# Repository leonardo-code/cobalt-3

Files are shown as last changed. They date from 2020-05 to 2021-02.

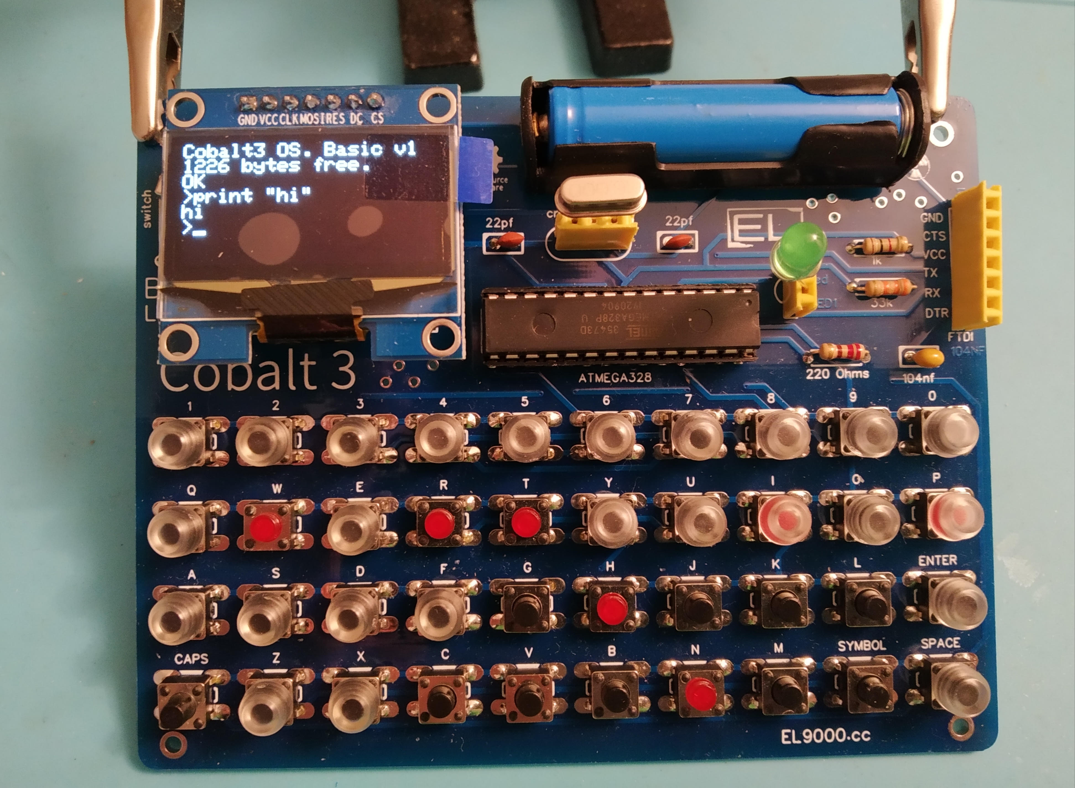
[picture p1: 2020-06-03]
img/Cobalt3.jpg

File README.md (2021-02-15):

# cobalt-3
Cobalt 3 pocket computer

by Leonardo Leoni

I wanted a pocket computer I can build myself to learn through-hole soldering and get a simple basic computer. There were a lot of projects out there, ok, but I needed a kit ready to mount, without having to look for components around the world.

The core component is the Atmega328, the keyboard is serial with tactile momentary switches and the display an is a SPI OLED type with the common SH1106 driver. A toggle switch and a led complete the Cobalt 3 (giving a name was the most cool part of the job).

I put all together in the design of a simple pcb and I used an Arduino IDE to compile the O.S. in C++ language. The O.S. can be loaded through a UART serial interface. The O.S. is composed of 3 parts: one to show data on the display (data output), one to manage the keyboard (data input), and last but not least, to elaborate the Basic Language instructions (data elaboration).

Project page:
http://el9000.cc/projects

Shop: https://www.tindie.com/products/el9000/cobalt-3-a-pocket-computer-diy/

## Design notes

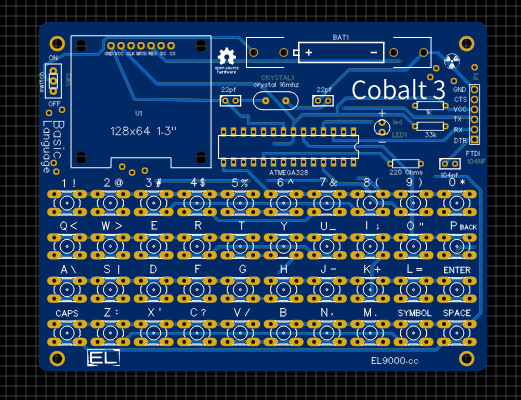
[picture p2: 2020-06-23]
doc/gerber/pcb.gif

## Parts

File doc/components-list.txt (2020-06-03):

1	×	Oled Display 128x64 SPI 7 pins
1	×	AAA battery holder
1	×	led
40	×	tactile momentary switches
1	×	220 Ohm resistor
1	×	1 K Ohm resistor
1	×	33 K Ohm resistor
1	×	AAA Li-Ion battery 3.7v 350-600 mAh
1	×	Crystal 16.000 MHz
2	×	22pf capacitor
1	×	104nf capacitor
1	×	atmega328p
1	×	socket 28 pin narrow
1	×	header 6 pin
1	×	toggle switch 3 pin

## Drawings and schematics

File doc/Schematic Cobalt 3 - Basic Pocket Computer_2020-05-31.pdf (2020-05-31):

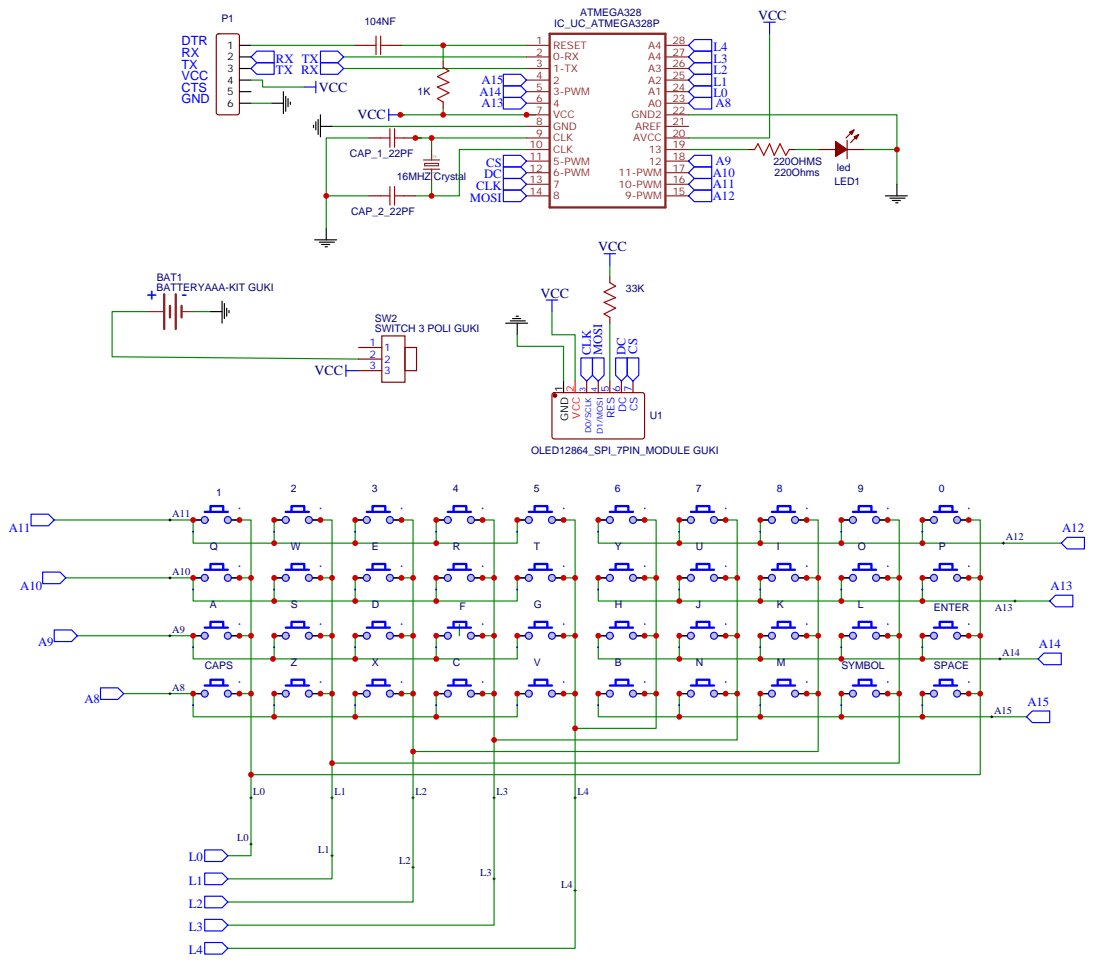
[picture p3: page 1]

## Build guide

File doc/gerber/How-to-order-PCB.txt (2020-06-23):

How to Order PCB

Please refer to:
https://docs.easyeda.com/en/PCB/Order-PCB

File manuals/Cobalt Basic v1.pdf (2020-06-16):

17/6/2020 | Cobalt Basic v1
el9000.cc/Cobalt_Basic_v1 | 1/7

## Cobalt Basic v1

# User Manual

by Leonardo Leoni

Why the Basic language?
The Basic language was the first language to be "user-friendly", easy to learn and to understand. It uses an interpreter, so you can write a command after the prompt and run it immediately. It was the first simple computer language and became very common in the home computer sector during the 80's.

What is the Cobalt Basic language?
Cobalt Basic is one version of the Tiny Basic language developed initially as Palo Alto Tiny Basic by Li-Chen Wang (1976) and it ran on either the 8080 or Z80 processor. Nowadays there are some very similar versions that run on ATmega328, some are the TOYOSHIKI Tiny BASIC for Arduino, the Tiny Basic 68k by Gordon Brandly, the Arduino Basic by Michael Field and the Tiny Basic Plus by Scott Lawrence. Many credits to those guys.
Cobalt Basic is nothing more that a simpler version, adapted to stay into a little atmega328 together with the display and keyboard libraries, leaving also the space for your program to be put in the memory.

What can Cobalt Basic do?
Ok, but again: why the Basic Langauge? Because it's the perfect language if you don't know anything about programming, because it's simple but complete. Think about that: with this computer language you can print words on the screen, give value to variables, make simple mathematical calculation, use subroutines, repeat commands also infinitely and do much more.

Does it include a standard keyboard?
Only two words about the keyboard. It's important to understand the keyboard layout, a QWERTY one but with several particularities, so take two minutes to give a look to the Cobalt 3 keyboard guide before using it.

Characters typed with the keyboard are lowercase, but the Cobalt Basic commands are stored in memory uppercase, so you can see the difference from what you type and what is stored. It's useful when you subsstitute a row of the program with another one. Type LIST command to see your program uppercase.
Example:

>10 prit "dog"
>run

Syntax Error
>10 print "dog"
>list
10 PRINT "dog"
>run
dog

OK
>_

"Syntax Error" is the error message when there's a mistake in your program.

So, what else, let's start with Cobalt Basic! Let's look together at the commands available!

Summary
Relational operators
Arithmetic operations
NEW - clears the last program RUN - executes the current program
LIST - prints the current program
LET - sets the value of a variable
IF - if expression is true, elaborates an istruction GOTO - continues execution at a given line number GOSUB - goes to a subroutine at a given line number RETURN - returns from a subroutine
REM - comments
FOR - loop block, uses TO and STEP
TO - the end value that stops the for loop
STEP - adds a different value in a for loop
NEXT - end of for block
INPUT - gives to the user the chance of insert a value for a variable PRINT - displays something on the screen, also "?"
STOP - ends the execution of the current program
BYE - exits, a soft reboot of the Cobalt device

Relational operators
The Cobalt Basic v1 has six relational operators used to compare two operands, obtaining a true/false result.
= equality
< less than
> greater than
<= less or equal
>= greater or equal
<> not equal

Arithmetic operations
The Cobalt Basic v1 can do four arithmetic operations. It can add, substruct, multiply and divide.
+ add
- substruct
* multiply
/ divide

NEW
Use this command at the Cobalt prompt when you want to clear the memory and start a new program. It cancels an old program, lines, or commands, clearing all.

>new
>list
OK

RUN
This is the command you need to launch the program you wrote.
A program is made of several rows, each one has an instruction to execute.
At the beginning of each row you can write the number of the row. If you do it, the row will be part of the current program.
The numbers are for ordering the statements of the program.
Without the number at the beginning of the row, the instruction will be executed immediately from the Cobalt Basic interpreter.

>run

See the example in the LET statement.

LIST
The statement is used to view the program you are typing or you finished.

>list

See the example in the STEP statement.

LET
This instruction assigns a value to a variable. The value could be a number or another variable.

>10 let p=1+7
>20 print p
>run
8
OK

IF
It checks if an expression is true, and if so, an inline instructions will be executed.

The relational operators are:
= equality
< less than
> greater than
<= less or equal
>= greater or equal
<> not equal

Examples:

>10 a=3
>20 if a > 2 print "hi"
>run
hi
OK

GOTO
The GOTO statement has the line number where the program execution will continue, jumping to that line.
Example:

>10 a=2
>20 a=a+1
>30 print a
>40 if a < 10 print a
>50 if a < 5 goto 20
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
GOSUB
The GOSUB statement has the line number where the program execution will continue, similar to GOTO, with a difference: the block that will be executed (subroutine) ends with the keyword RETURN.
So in this case, the excution will jump back to the line after the GOSUB statement. Consider also the use of STOP to exit the program execution.

>10 z = 2
>20 z = z + 1
>30 gosub 300
>40 if z < 5 goto 20
>50 stop
>300 rem subroutine for printing >310 print z
>320 return
>run
3
4
5
OK

RETURN
The RETURN keyword indicates the end of a subroutine called by a GOSUB.

REM
After a line number, the word REM is used to write a comment, in this way:

>20 rem Program about financial calculation

FOR
The FOR keyword is used for repeating a block of istructions. How does it work?

Let's look at the example below.

>10 for t=2 to 5
>20 print t
>30 next t
>run
2
3
4
5
OK

After the FOR keyword, "t=2" is the initial value of "t", while "to 5" means the FOR block will be repeated until the value of "t" will be "5".
In the FOR block there's the command "print t", that means the value of "t" will be displayed.
The row with "next t" indicates the end of the loop.

TO
In a FOR loop, after the starting value, the block will be repeated until the end value, showed after the "to" keyword.
See the example in the FOR statement.

STEP
Substituting the row number 10, this is what will happen:

>10 for t=2 to 10 step 2
>list
10 FOR T=2 TO 5
20 PRINT T
30 NEXT T
>run
2
4
6
8
10
OK

That's because adding "step 2" means add "2" to the value of "t";

NEXT
The statement that marks the end of a FOR loop. It means "next round"; Example:

>30 next t

INPUT
With this command a usser can assign a number to a variable.
Below, when I run the program, I write "2" after the "?", and the program assigns it to the variable a. Then it prints its value.
See also the use of the command LIST.

>10 input a
>20 print a
>list
10 INPUT A
20 PRINT A
OK
>run
?2
2
OK
>_

PRINT
Used to make the program write something on the screen. After the execution,the system shows the prompt and the cursor.

>print "hello"
hello
>_

If you add a semicolon at the end, the Cobalt Basic interpreter writes the commands inline, so you have:

>print "hello";
hello>_

STOP
This command ends the execution of the program. See the example in the GOSUB statement.

BYE
This is a system command, you can use it if you need a soft reboot of the system with the reset of the memory.

>bye
1226 bytes free.
OK
>_

Thanks for reading.

Cheers,

Leonardo

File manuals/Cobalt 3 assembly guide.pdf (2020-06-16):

17/6/2020 | Cobalt 3 assembly guide

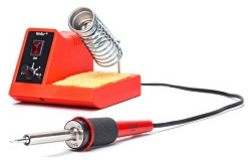
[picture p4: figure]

el9000.cc/Cobalt_3_assembly_guide | 1/10

## Cobalt 3

# Assembly guide

by Leonardo Leoni

Introduction
First of all note that this pocket computer is for hobby use, it is not for industrial use.
Cobalt 3 has been designed to give everyone the opportunity to build their own computer in the easiest way possible. This allows you to have fun learning and building something that is complete and functional, within limits.

Assembling a computer is very complex even if it is supplied as a kit to assemble. For this reason I realised this project: to give everyone the opportunity to make a computer on their own. And to make it easier, this little computer is a sbc (single board computer). This means that all the necessary components are on a single electronic board.

Also included are a display and a keyboard, to avoid having to plug it into another computer to see what goes on the screen or to type commands.
A battery is also included in the card, so you can put Cobalt 3 in your pocket and carry it with you, when you go out or go to school or work.

Required Skills
Assembling. Although the list of components is kept to the minimum, there are about 200 soldering points, which means that you need some experience. I started from scratch, and I took other less complex kits to learn how to solder.
So you should be able to assemble beforehand that this step has been taken.

Tools

You just need normal soldering tools as a soldering iron, a magnifying glass, and a third-hand tool for holding the board, etc

Here a link to an easy soldering tutorial for beginners:
Soldering Tutorial for Beginners: Five Easy Steps (https://www.youtube.com/watch?v=Qps9woUGkvI)

Components
Note that components and board images can be different in shape and color.

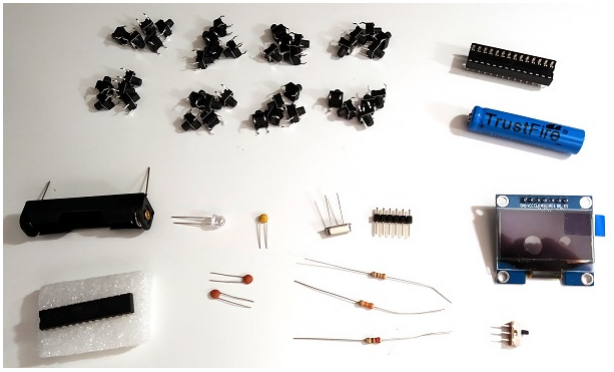
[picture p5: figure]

Try to visualize where the various components go on the board. Then assemble the board in different steps.
I suggest to start with the smaller parts.

List:
1 × atmega328p
1 × Oled Display 128x64 SPI 7 pins
1 × AAA battery holder
1 × socket 28 pin narrow
1 × AAA Li-Ion battery 3.7v 350-600 mAh 1 × Crystal 16.000 MHz
1 × led
1 × 220 Ohm resistor
1 × 1 K Ohm resistor
1 × 33 K Ohm resistor
2 × 22pf capacitor
1 × 104nf capacitor
1 × header 6 pin
1 × toggle switch 3 pin
40 × tactile momentary switches

This is how It will look at the end.

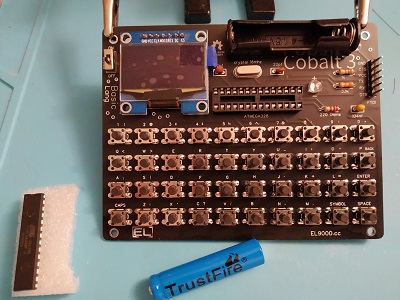
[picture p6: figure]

1) Tactile momentary switch

First insert and solder all 40 switches on the keyboard

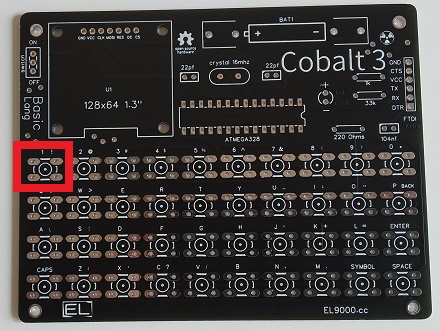
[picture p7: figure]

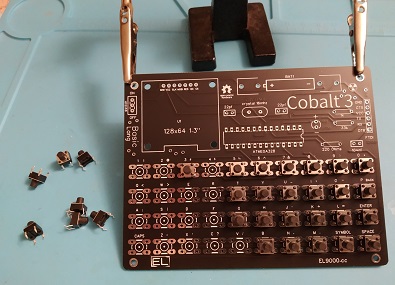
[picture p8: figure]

2) Resistors and capacitors

In the green rectangle 2 x capacitors 22pf
In the red one 1 x capacitor 104nf
In the blue one 3 x resistors, from the top to bottom:
- 1K Ohm resistor
- 33K Ohm resistor
- 220 Ohm resistor

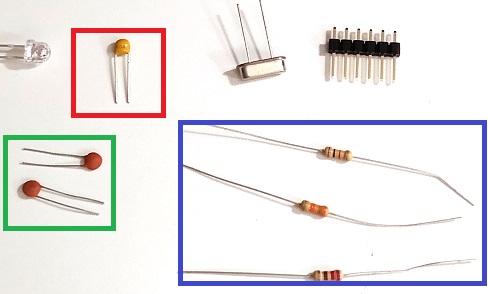
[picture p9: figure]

Put the resistors on the board in the same order. Match the color of the rectangles.

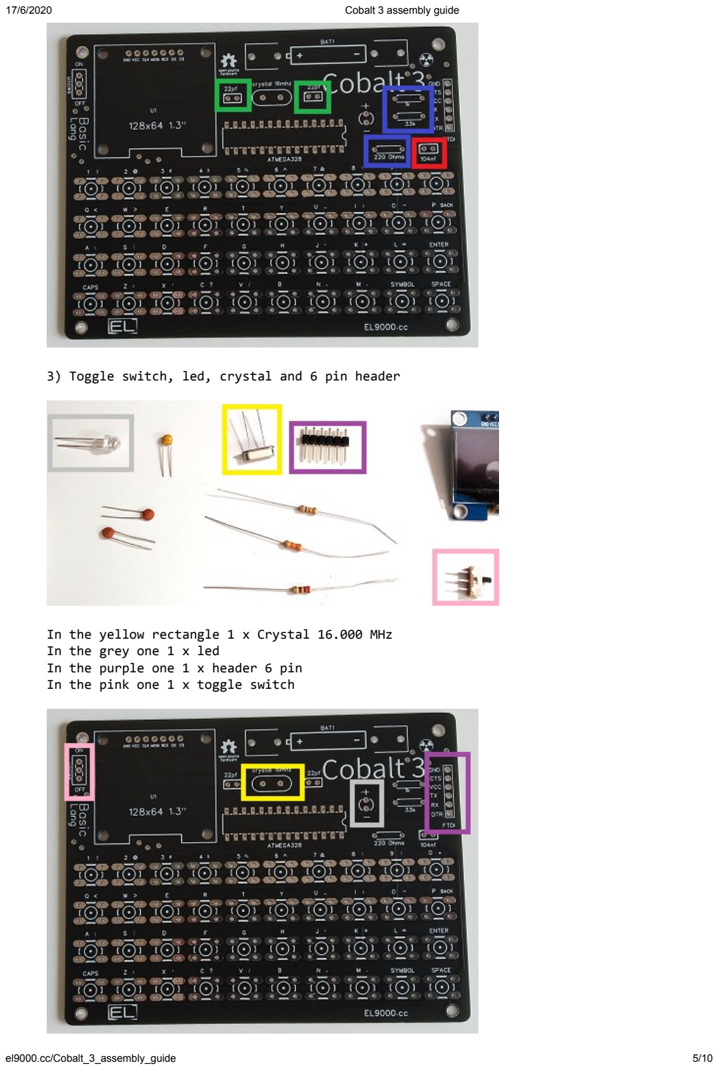
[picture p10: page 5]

3) Toggle switch, led, crystal and 6 pin header

In the yellow rectangle 1 x Crystal 16.000 MHz In the grey one 1 x led
In the purple one 1 x header 6 pin
In the pink one 1 x toggle switch

Match the color of the rectangles.
Pay attention to the legs of the led, the longer is the positive, the shorter the negative.
4) Microcontroller socket and battery holder

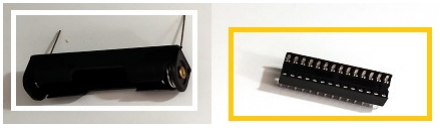
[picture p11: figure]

In the white rectangle 1 x battery holder In the orange one 1 x socket

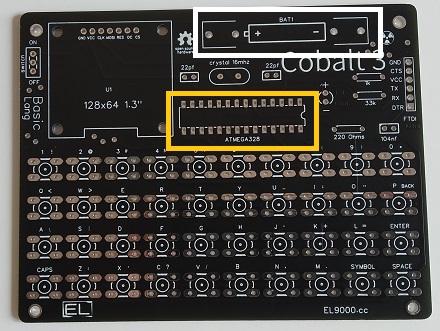
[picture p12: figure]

Pay attention to the right position of those components.
There is a notch on the socket and on the atmega328 that shows you what the right fitting is.
Fit correctly the positive and the negative side of the battery holder.
4) Oled display

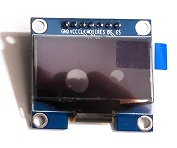
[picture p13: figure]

Fit it in the light blue color rectangle. Pins name can be different, don't worry about it, only the right position of the component is important.

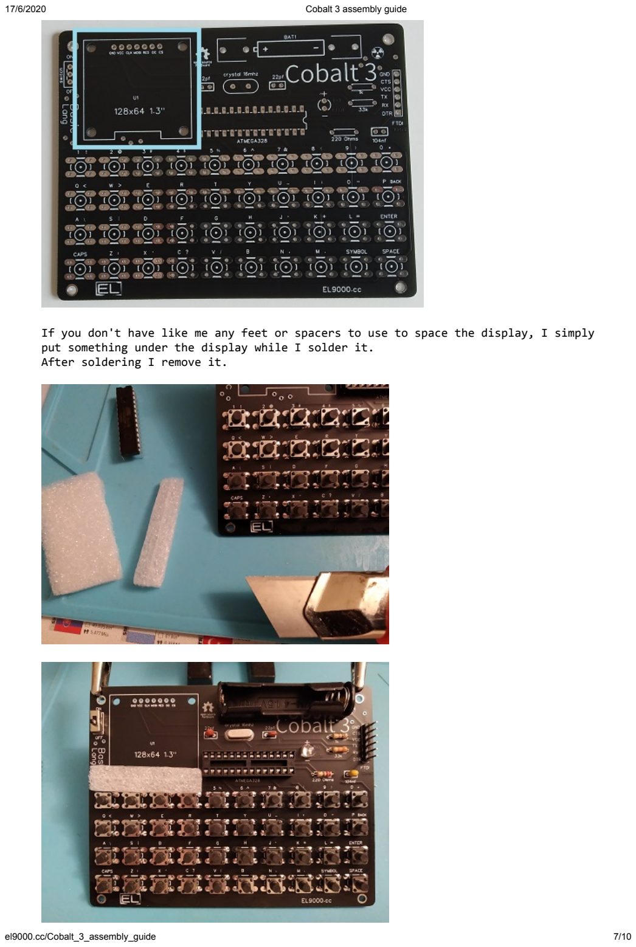
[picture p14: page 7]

If you don't have like me any feet or spacers to use to space the display, I simply put something under the display while I solder it.
After soldering I remove it.

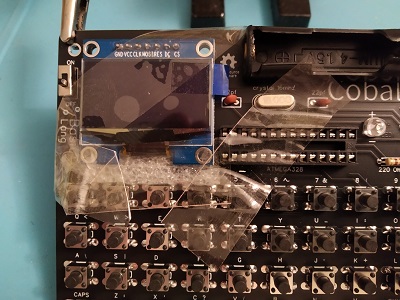
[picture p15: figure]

Finishing and Cleaning
When you're done assembling, fit the microcontroller in the socket and then clean the board.
Cleaning the board is a good practice, I use Isopropyl alcohol because is highly efficient in dissolving most commonly found PCB contaminants, it's also electrically non-conducting and evaporates quickly.

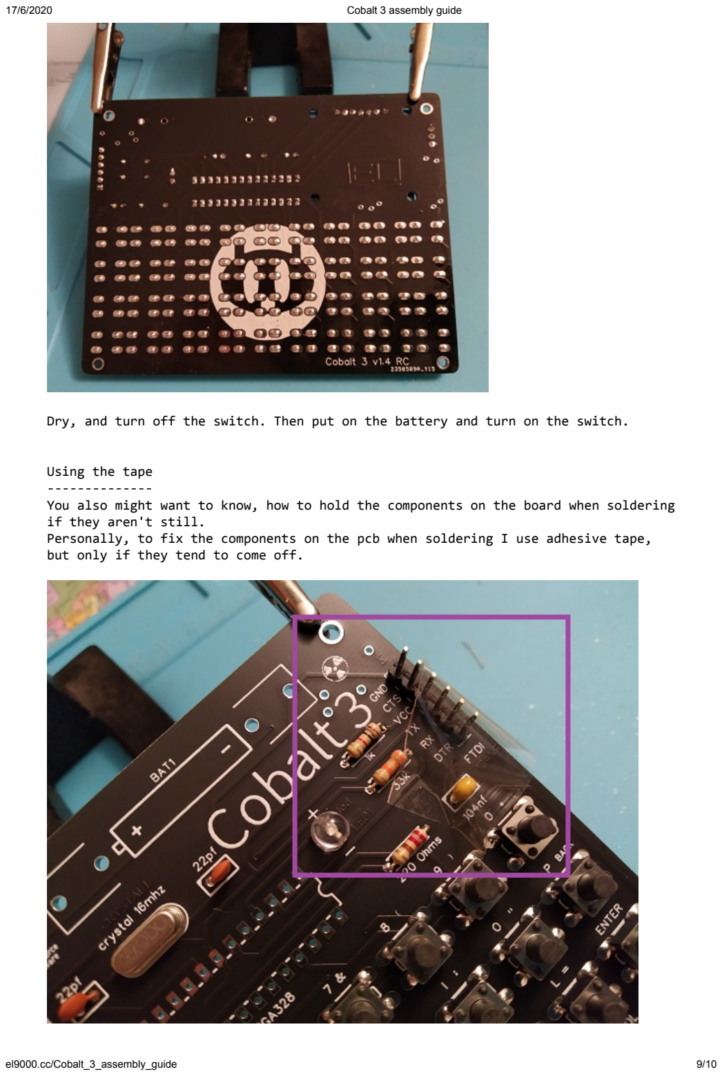
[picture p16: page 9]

Dry, and turn off the switch. Then put on the battery and turn on the switch.

Using the tape
You also might want to know, how to hold the components on the board when soldering if they aren't still.
Personally, to fix the components on the pcb when soldering I use adhesive tape, but only if they tend to come off.

How to solve problems
How to troubleshoot a circuit board? There's a nice video here:
Detecting pcb failures (https://www.youtube.com/watch?v=GgHxaTdYtj4)

The most important tool to find any problems is the multimeter, but in this case, given the simplicity of the circuit, any problem will generally boil down to the bad positiong of the components or to the badly made solder joints.

So do an accurate visual inspection, check that all the components are positioned correctly, and if they are, then use the magnifying glass to verify that the solder joints have been well made.

I used this guide, by Zakariah Martin-Taylor:
Soldering tips and tricks (https://www.risingsunfpv.com.au/blogs/helpful-guides/soldering-tips-and-tricks)

Thanks for reading. Happy soldering!

Cheers,

Leonardo

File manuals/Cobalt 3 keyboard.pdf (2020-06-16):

17/6/2020 | Cobalt 3 keyboard
el9000.cc/Cobalt_3_keyboard | 1/1

## Cobalt 3

# Keyboard guide

by Leonardo Leoni

Why this guide?
Cobalt 3 is a pocket computer with a QWERTY type keyboard, with some particularities.
Below the keyboard layout with the complete keymap.
| | 1 | | | 2 | | | 3 | | | 4 | | | 5 | | | 6 | | | 7 | | | 8 | | | 9 | | | 0 | |
| | Q | | | W | | | E | | | R | | | T | | | Y | | | U | | | I | | | O | | | P | |
| | A | | | S | | | D | | | F | | | G | | | H | | | J | | | K | | | L | | ENTER |
| CAPS | | Z | | | X | | | C | | | V | | | B | | | N | | | M | |SYMBOL | SPACE |

The key SYMBOL is not enabled in Cobalt 3, if you press it, '#' will be displayed.

The key CAPS is used to type special characters. You need to type before the key CAPS, and then the other key, together.
Hold the keys for one second to make it working.
Below there's the map of the layout of special characters when you type the key CAPS.
| | ! | | | @ | | | # | | | $ | | | % | | | ^ | | | & | | | ( | | | ) | | | * | |
| | < | | | > | | | | | | | | | | | _ | | | ; | | | " | | DEL |
| | \ | | | | | | | | | | | | | | | | | | | - | | | + | | | = | | | | |
| | | | | : | | | ' | | | ? | | | / | | | * | | | , | | | . | | | | | | | |

Note that characters typed with the keyboard are lowercase.

Thanks for reading.

Cheers,

Leonardo

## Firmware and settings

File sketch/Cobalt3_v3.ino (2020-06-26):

/* Cobalt 3 OS v3.0
   This fancy opensource OS can manage the display and the keyboard of 'Cobalt 3' pocket computer, and runs a modified version of tiny basic
   Leonardo Leoni - www.el9000.cc - 18th June 2020
   Licensed under the MIT license: https://opensource.org/licenses/MIT
*/
#include <Keypad.h>
#include <SPI.h>

#define SERIAL_DISPLAY

// ASCII Characters
#define CR  '\r'
#define NL  '\n'
#define TAB '\t'
#define BELL  '\b'
#define DEL '\177'
#define SPACE   ' '
#define CTRLC 0x03
#define CTRLH 0x08
#define CTRLS 0x13
#define CTRLX 0x18

typedef short unsigned LINENUM;

// C Macros
#define car(x)             (((object *) (x))->car)
#define cdr(x)             (((object *) (x))->cdr)

const int RAMsize = RAMEND - RAMSTART + 1;
const int workspacesize = (RAMsize - RAMsize/4 - 280)/4;
const int buflen = 17;  // Length of longest symbol + 1

static uint8_t Cursor = 0;

enum function {  ENDFUNCTIONS };

// Typedefs

typedef struct sobject {
  union {
    struct {
      sobject *car;
      sobject *cdr;
    };
    struct {
       union {
        unsigned int name;
      };
    };
  };
} object;

typedef object *(*fn_ptr_type)(object *, object *);

typedef struct {
  const char *string;
} tbl_entry_t;

object workspace[workspacesize];

char buffer[buflen+1];

char *lookupstring (unsigned int name);
void Display (char c);

// ------------------------------------------------------
// keyboard config start
// ------------------------------------------------------
const byte ROWS = 8; //four rows
const byte COLS = 5; //four columns

char keys[ROWS][COLS] = {
  {'1','2','3','4','5'},
  {'q','w','e','r','t'},
  {'a','s','d','f','g'},
  {'@','z','x','c','v'},
  {'0','9','8','7','6'},
  {'p','o','i','u','y'},
  {'\r','l','k','j','h'},
  {' ','#','m','n','b'}
};

byte rowPins[ROWS] = {10, 11, 12, 14, 9, 4, 3, 2 }; //connect to the row pinouts of the keypad
byte colPins[COLS] = {15, 16, 17, 18, 19}; //connect to the column pinouts of the keypad

Keypad keypad = Keypad( makeKeymap(keys), rowPins, colPins, ROWS, COLS );
// ------------------------------------------------------
// keyboard config end
// ------------------------------------------------------

/*
 * modified tiny basic start
 ***********************************************************/
// Keyword table and constants - the last character has 0x80 added to it
static unsigned char keywords[] =
{
  'L', 'I', 'S', 'T' + 0x80,
  'L', 'O', 'A', 'D' + 0x80,
  'N', 'E', 'W' + 0x80,
  'R', 'U', 'N' + 0x80,
  'S', 'A', 'V', 'E' + 0x80,
  'N', 'E', 'X', 'T' + 0x80,
  'L', 'E', 'T' + 0x80,
  'I', 'F' + 0x80,
  'G', 'O', 'T', 'O' + 0x80,
  'G', 'O', 'S', 'U', 'B' + 0x80,
  'R', 'E', 'T', 'U', 'R', 'N' + 0x80,
  'R', 'E', 'M' + 0x80,
  'F', 'O', 'R' + 0x80,
  'I', 'N', 'P', 'U', 'T' + 0x80,
  'P', 'R', 'I', 'N', 'T' + 0x80,
  'P', 'O', 'K', 'E' + 0x80,
  'S', 'T', 'O', 'P' + 0x80,
  'B', 'Y', 'E' + 0x80,
  0
};

#define KW_LIST   0
#define KW_LOAD   1
#define KW_NEW    2
#define KW_RUN    3
#define KW_SAVE   4
#define KW_NEXT   5
#define KW_LET    6
#define KW_IF     7
#define KW_GOTO   8
#define KW_GOSUB  9
#define KW_RETURN 10
#define KW_REM    11
#define KW_FOR    12
#define KW_INPUT  13
#define KW_PRINT  14
#define KW_POKE   15
#define KW_STOP   16
#define KW_BYE    17
#define KW_DEFAULT  18

struct stack_for_frame
{
  char frame_type;
  char for_var;
  short int terminal;
  short int step;
  unsigned char *current_line;
  unsigned char *txtpos;
};

struct stack_gosub_frame
{
  char frame_type;
  unsigned char *current_line;
  unsigned char *txtpos;
};

static unsigned char func_tab[] =
{
  'P', 'E', 'E', 'K' + 0x80,
  'A', 'B', 'S' + 0x80,
  0
};
#define FUNC_PEEK    0
#define FUNC_ABS   1
#define FUNC_UNKNOWN 2

static unsigned char to_tab[] =
{
  'T', 'O' + 0x80,
  0
};

static unsigned char step_tab[] =
{
  'S', 'T', 'E', 'P' + 0x80,
  0
};

static unsigned char relop_tab[] =
{
  '>', '=' + 0x80,
  '<', '>' + 0x80,
  '>' + 0x80,
  '=' + 0x80,
  '<', '=' + 0x80,
  '<' + 0x80,
  0
};

#define RELOP_GE    0
#define RELOP_NE    1
#define RELOP_GT    2
#define RELOP_EQ    3
#define RELOP_LE    4
#define RELOP_LT    5
#define RELOP_UNKNOWN 6

#define VAR_SIZE sizeof(short int) // Size of variables in bytes

static unsigned char memory[1280];
static unsigned char *txtpos, *list_line;
static unsigned char expression_error;
static unsigned char *tempsp;
static unsigned char *stack_limit;
static unsigned char *program_start;
static unsigned char *program_end;
static unsigned char *variables_table;
static unsigned char *current_line;
static unsigned char *sp;
#define STACK_GOSUB_FLAG 'G'
#define STACK_FOR_FLAG 'F'
static unsigned char table_index;
static LINENUM linenum;

static const unsigned char okmsg[]    = "OK";
static const unsigned char badlinemsg[]   = "Invalid line number";
static const unsigned char invalidexprmsg[] = "Invalid expression";
static const unsigned char syntaxmsg[] = "Syntax Error";
static const unsigned char badinputmsg[] = "\nBad number";
static const unsigned char nomemmsg[] = "Not enough memory!";
static const unsigned char memorymsg[]  = " bytes free.";
static const unsigned char breakmsg[] = "break!";
static const unsigned char stackstuffedmsg[] = "Stack is stuffed!\n";
static const unsigned char unimplimentedmsg[] = "Unimplemented";
static const unsigned char backspacemsg[]   = "\b \b";

static int inchar(void);
static void outchar(unsigned char c);
static void line_terminator(void);
static short int expression(void);
static unsigned char breakcheck(void);

/***************************************************************************/
static void ignore_blanks(void)
{
  while(*txtpos == SPACE || *txtpos == TAB)
    txtpos++;
}

/***************************************************************************/
static void scantable(unsigned char *table)
{
  int i = 0;
  ignore_blanks();
  table_index = 0;
  while(1)
  {
    // Run out of table entries?
    if(table[0] == 0)
      return;

    // Do we match this character?
    if(txtpos[i] == table[0])
    {
      i++;
      table++;
    }
    else
    {
      // do we match the last character of keywork (with 0x80 added)? If so, return
      if(txtpos[i] + 0x80 == table[0])
      {
        txtpos += i + 1; // Advance the pointer to following the keyword
        ignore_blanks();
        return;
      }

      // Forward to the end of this keyword
      while((table[0] & 0x80) == 0)
        table++;

      // Now move on to the first character of the next word, and reset the position index
      table++;
      table_index++;
      i = 0;
    }
  }
}

/***************************************************************************/
static void pushb(unsigned char b)
{
  sp--;
  *sp = b;
}

/***************************************************************************/
static unsigned char popb()
{
  unsigned char b;
  b = *sp;
  sp++;
  return b;
}

/***************************************************************************/
static void printnum(int num)
{
  int digits = 0;

  if(num < 0)
  {
    num = -num;
    outchar('-');
  }

  do
  {
    pushb(num % 10 + '0');
    num = num / 10;
    digits++;
  }
  while (num > 0);

  while(digits > 0)
  {
    outchar(popb());
    digits--;
  }
}

/***************************************************************************/
static unsigned short testnum(void)
{
  unsigned short num = 0;
  ignore_blanks();

  while(*txtpos >= '0' && *txtpos <= '9' )
  {
    // Trap overflows
    if(num >= 0xFFFF / 10)
    {
      num = 0xFFFF;
      break;
    }

    num = num * 10 + *txtpos - '0';
    txtpos++;
  }
  return  num;
}

/***************************************************************************/
unsigned char check_statement_end(void)
{
  ignore_blanks();
  return (*txtpos == NL) || (*txtpos == ':');
}

/***************************************************************************/
static void printmsgNoNL(const unsigned char *msg) // ka
{
  while(*msg)
  {
    outchar(*msg);
    msg++;
  }
}

/***************************************************************************/
static unsigned char print_quoted_string(void)
{
  int i = 0;
  unsigned char delim = *txtpos;
  if(delim != '"' && delim != '\'')
    return 0;
  txtpos++;

  // Check we have a closing delimiter
  while(txtpos[i] != delim)
  {
    if(txtpos[i] == NL)
      return 0;
    i++;
  }

  // Print the characters
  while(*txtpos != delim)
  {
    outchar(*txtpos);
    txtpos++;
  }
  txtpos++; // Skip over the last delimiter
  ignore_blanks();

  return 1;
}

/***************************************************************************/
static void printmsg(const unsigned char *msg)
{
  printmsgNoNL(msg);
  line_terminator();
}

/***************************************************************************/
unsigned char getln(char prompt)
{
  //if (prompt != '>') // without basic language, OS cursor
    outchar(prompt);
  txtpos = program_end + sizeof(LINENUM);

  while(1)
  {
    char c = inchar();
    switch(c)
    {
      case CR:
      case NL:
        line_terminator();
        // Terminate all strings with a NL
        txtpos[0] = NL;
        return 1;
      case CTRLC:
        return 0;
      case CTRLH:
        if(txtpos == program_end)
          break;
        txtpos--;
        printmsgNoNL(backspacemsg);
        break;
      default:
        // We need to leave at least one space to allow us to shuffle the line into order
        if(txtpos == sp - 2)
          outchar(BELL);
        else
        {
          txtpos[0] = c;
          txtpos++;
          outchar(c);
        }
    }
  }
}

/***************************************************************************/
static unsigned char *findline(void)
{
  unsigned char *line = program_start;
  while(1)
  {
    if(line == program_end)
      return line;

    if(((LINENUM *)line)[0] >= linenum)
      return line;

    // Add the line length onto the current address, to get to the next line;
    line += line[sizeof(LINENUM)];
  }
}

/***************************************************************************/
static void toUppercaseBuffer(void)
{
  unsigned char *c = program_end + sizeof(LINENUM);
  unsigned char quote = 0;

  while(*c != NL)
  {
    // Are we in a quoted string?
    if(*c == quote)
      quote = 0;
    else if(*c == '"' || *c == '\'')
      quote = *c;
    else if(quote == 0 && *c >= 'a' && *c <= 'z')
      *c = *c + 'A' - 'a';
    c++;
  }
}

/***************************************************************************/
void printline()
{
  LINENUM line_num;

  line_num = *((LINENUM *)(list_line));
  list_line += sizeof(LINENUM) + sizeof(char);

  // Output the line */
  printnum(line_num);
  outchar(' ');
  while(*list_line != NL)
  {
    outchar(*list_line);
    list_line++;
  }
  list_line++;
  line_terminator();
}

/***************************************************************************/
static short int expr4(void)
{
  short int a = 0;

  if(*txtpos == '0')
  {
    txtpos++;
    a = 0;
    goto success;
  }

  if(*txtpos >= '1' && *txtpos <= '9')
  {
    do
    {
      a = a * 10 + *txtpos - '0';
      txtpos++;
    }
    while(*txtpos >= '0' && *txtpos <= '9');
    goto success;
  }

  // Is it a function or variable reference?
  if(txtpos[0] >= 'A' && txtpos[0] <= 'Z')
  {
    // Is it a variable reference (single alpha)
    if(txtpos[1] < 'A' || txtpos[1] > 'Z')
    {
      a = ((short int *)variables_table)[*txtpos - 'A'];
      txtpos++;
      goto success;
    }

    // Is it a function with a single parameter
    scantable(func_tab);
    if(table_index == FUNC_UNKNOWN)
      goto expr4_error;

    unsigned char f = table_index;

    if(*txtpos != '(')
      goto expr4_error;

    txtpos++;
    a = expression();
    if(*txtpos != ')')
      goto expr4_error;
    txtpos++;
    switch(f)
    {
      case FUNC_PEEK:
        a =  memory[a];
        goto success;
      case FUNC_ABS:
        if(a < 0)
          a = -a;
        goto success;
    }
  }

  if(*txtpos == '(')
  {
    txtpos++;
    a = expression();
    if(*txtpos != ')')
      goto expr4_error;

    txtpos++;
    goto success;
  }

expr4_error:
  expression_error = 1;
success:
  ignore_blanks();
  return a;
}

/***************************************************************************/
static short int expr3(void)
{
  short int a, b;

  a = expr4();
  while(1)
  {
    if(*txtpos == '*')
    {
      txtpos++;
      b = expr4();
      a *= b;
    }
    else if(*txtpos == '/')
    {
      txtpos++;
      b = expr4();
      if(b != 0)
        a /= b;
      else
        expression_error = 1;
    }
    else
      return a;
  }
}

/***************************************************************************/
static short int expr2(void)
{
  short int a, b;

  if(*txtpos == '-' || *txtpos == '+')
    a = 0;
  else
    a = expr3();

  while(1)
  {
    if(*txtpos == '-')
    {
      txtpos++;
      b = expr3();
      a -= b;
    }
    else if(*txtpos == '+')
    {
      txtpos++;
      b = expr3();
      a += b;
    }
    else
      return a;
  }
}
/***************************************************************************/
static short int expression(void)
{
  short int a, b;

  a = expr2();
  // Check if we have an error
  if(expression_error)  return a;

  scantable(relop_tab);
  if(table_index == RELOP_UNKNOWN)
    return a;

  switch(table_index)
  {
    case RELOP_GE:
      b = expr2();
      if(a >= b) return 1;
      break;
    case RELOP_NE:
      b = expr2();
      if(a != b) return 1;
      break;
    case RELOP_GT:
      b = expr2();
      if(a > b) return 1;
      break;
    case RELOP_EQ:
      b = expr2();
      if(a == b) return 1;
      break;
    case RELOP_LE:
      b = expr2();
      if(a <= b) return 1;
      break;
    case RELOP_LT:
      b = expr2();
      if(a < b) return 1;
      break;
  }
  return 0;
}

/***************************************************************************/

// Read/Evaluate/Print loop
void loop()
{
  unsigned char *start;
  unsigned char *newEnd;
  unsigned char linelen;

/*  other tiny basic modification start
 *   
 */
  
  variables_table = memory;
  program_start = memory + 27 * VAR_SIZE;
  program_end = program_start;
  sp = memory + sizeof(memory); // Needed for printnum
  printnum(sp - program_end);

  Cursor = 1;
  printmsg(memorymsg);
  
warmstart:     
  // this signifies that it is running in 'direct' mode.
  current_line = 0;
  sp = memory + sizeof(memory);
  printmsg(okmsg);

prompt:

  while(!getln('>'))
    line_terminator();

  toUppercaseBuffer();
  txtpos = program_end + sizeof(unsigned short);

  // Find the end of the freshly entered line
  while(*txtpos != NL)
    txtpos++;

  // Move it to the end of program_memory
  {
    unsigned char *dest;
    dest = sp - 1;
    while(1)
    {
      *dest = *txtpos;
      if(txtpos == program_end + sizeof(unsigned short))
        break;
      dest--;
      txtpos--;
    }
    txtpos = dest;
  }

  // Now see if we have a line number
  linenum = testnum();
  ignore_blanks();
  if(linenum == 0)
    goto direct;

  if(linenum == 0xFFFF)
    goto badline;

  // Find the length of what is left, including the (yet-to-be-populated) line header
  linelen = 0;
  while(txtpos[linelen] != NL)
    linelen++;
  linelen++; // Include the NL in the line length
  linelen += sizeof(unsigned short) + sizeof(char); // Add space for the line number and line length

  // Now we have the number, add the line header.
  txtpos -= 3;
  *((unsigned short *)txtpos) = linenum;
  txtpos[sizeof(LINENUM)] = linelen;

  // Merge it into the rest of the program
  start = findline();

  // If a line with that number exists, then remove it
  if(start != program_end && *((LINENUM *)start) == linenum)
  {
    unsigned char *dest, *from;
    unsigned tomove;

    from = start + start[sizeof(LINENUM)];
    dest = start;

    tomove = program_end - from;
    while( tomove > 0)
    {
      *dest = *from;
      from++;
      dest++;
      tomove--;
    }
    program_end = dest;
  }

  if(txtpos[sizeof(LINENUM) + sizeof(char)] == NL) // If the line has no txt, it was just a delete
    goto prompt;

  // Make room for the new line, either all in one hit or lots of little shuffles
  while(linelen > 0)
  {
    unsigned int tomove;
    unsigned char *from, *dest;
    unsigned int space_to_make;

    space_to_make = txtpos - program_end;

    if(space_to_make > linelen)
      space_to_make = linelen;
    newEnd = program_end + space_to_make;
    tomove = program_end - start;

    // Source and destination - as these areas may overlap we need to move bottom up
    from = program_end;
    dest = newEnd;
    while(tomove > 0)
    {
      from--;
      dest--;
      *dest = *from;
      tomove--;
    }

    // Copy over the bytes into the new space
    for(tomove = 0; tomove < space_to_make; tomove++)
    {
      *start = *txtpos;
      txtpos++;
      start++;
      linelen--;
    }
    program_end = newEnd;
  }
  goto prompt;

unimplemented:
  printmsg(unimplimentedmsg);
  goto prompt;

badline:
  printmsg(badlinemsg);
  goto prompt;
invalidexpr:
  printmsg(invalidexprmsg);
  goto prompt;
syntaxerror:
  //Cursor = 1; delete the cursor before syntx error or ...
  printmsg(syntaxmsg); // ok
  if(current_line != (void *)0)
  {
    unsigned char tmp = *txtpos;
    if(*txtpos != NL)
      *txtpos = '^';
    list_line = current_line;
    printline();
    *txtpos = tmp;
  }
  line_terminator();
  goto prompt;

stackstuffed:
  printmsg(stackstuffedmsg);
  goto warmstart;
nomem:
  printmsg(nomemmsg);
  goto warmstart;

run_next_statement:
  while(*txtpos == ':')
    txtpos++;
  ignore_blanks();
  if(*txtpos == NL)
    goto execnextline;
  goto interperateAtTxtpos;

direct:
  txtpos = program_end + sizeof(LINENUM);
  if(*txtpos == NL)
    goto prompt;

interperateAtTxtpos:
  if(breakcheck())
  {
    printmsg(breakmsg);
    goto warmstart;
  }

  scantable(keywords);
  ignore_blanks();

  switch(table_index)
  {
    case KW_LIST:
      goto list;
    case KW_LOAD:
      goto unimplemented; 
    case KW_NEW:
      if(txtpos[0] != NL)
        goto syntaxerror;
      program_end = program_start;
      goto prompt;
    case KW_RUN:
      current_line = program_start;
      goto execline;
    case KW_SAVE:
      goto unimplemented; 
    case KW_NEXT:
      goto next;
    case KW_LET:
      goto assignment;
    case KW_IF:
    {
      short int val;
      expression_error = 0;
      val = expression();
      if(expression_error || *txtpos == NL)
        goto invalidexpr;
      if(val != 0)
        goto interperateAtTxtpos;
      goto execnextline;
    }
    case KW_GOTO:
      expression_error = 0;
      linenum = expression();
      if(expression_error || *txtpos != NL)
        goto invalidexpr;
      current_line = findline();
      goto execline;

    case KW_GOSUB:
      goto gosub;
    case KW_RETURN:
      goto gosub_return;
    case KW_REM:
      goto execnextline;  // Ignore line completely
    case KW_FOR:
      goto forloop;
    case KW_INPUT:
      goto input;
    case KW_PRINT:
      goto print;
    case KW_POKE:
      goto poke;
    case KW_STOP:
      // This is the easy way to end - set the current line to the end of program attempt to run it
      if(txtpos[0] != NL)
        goto syntaxerror;
      current_line = program_end;
      goto execline;
    case KW_BYE:
      // Leave the basic interperater
      return;
    case KW_DEFAULT:
      goto assignment;
    default:
      break;
  }

execnextline:
  if(current_line == (void *)0)   // Processing direct commands?
    goto prompt;
  current_line +=  current_line[sizeof(LINENUM)];

execline:
  if(current_line == program_end) // Out of lines to run
    goto warmstart;
  txtpos = current_line + sizeof(LINENUM) + sizeof(char);
  goto interperateAtTxtpos;

input:
  {
    unsigned char isneg = 0;
    short int *var;
    ignore_blanks();
    if(*txtpos < 'A' || *txtpos > 'Z')
      goto syntaxerror;
    var = ((short int *)variables_table) + *txtpos - 'A';
    txtpos++;
    if(!check_statement_end())
      goto syntaxerror;
again:
    if(!getln('?'))
      goto warmstart;

    // Go to where the buffer is read
    txtpos = program_end + sizeof(LINENUM);
    if(*txtpos == '-')
    {
      isneg = 1;
      txtpos++;
    }

    *var = 0;
    do
    {
      *var = *var * 10 + *txtpos - '0';
      txtpos++;
    }
    while(*txtpos >= '0' && *txtpos <= '9');
    ignore_blanks();
    if(*txtpos != NL)
    {
      printmsg(badinputmsg);
      goto again;
    }

    if(isneg)
      *var = -*var;

    goto run_next_statement;
  }
forloop:
  {
    unsigned char var;
    short int initial, step, terminal;

    if(*txtpos < 'A' || *txtpos > 'Z')
      goto syntaxerror;
    var = *txtpos;
    txtpos++;

    scantable(relop_tab);
    if(table_index != RELOP_EQ)
      goto syntaxerror;

    expression_error = 0;
    initial = expression();
    if(expression_error)
      goto invalidexpr;

    scantable(to_tab);
    if(table_index != 0)
      goto syntaxerror;

    terminal = expression();
    if(expression_error)
      goto invalidexpr;

    scantable(step_tab);
    if(table_index == 0)
    {
      step = expression();
      if(expression_error)
        goto invalidexpr;
    }
    else
      step = 1;
    if(!check_statement_end())
      goto syntaxerror;

    if(!expression_error && *txtpos == NL)
    {
      struct stack_for_frame *f;
      if(sp + sizeof(struct stack_for_frame) < stack_limit)
        goto nomem;

      sp -= sizeof(struct stack_for_frame);
      f = (struct stack_for_frame *)sp;
      ((short int *)variables_table)[var - 'A'] = initial;
      f->frame_type = STACK_FOR_FLAG;
      f->for_var = var;
      f->terminal = terminal;
      f->step     = step;
      f->txtpos   = txtpos;
      f->current_line = current_line;
      goto run_next_statement;
    }
  }
  goto syntaxerror;
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
